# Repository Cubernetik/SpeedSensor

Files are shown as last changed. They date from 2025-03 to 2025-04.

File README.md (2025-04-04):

# ESP32 Timer-Based Pulse Distance Measurement

This is the source code to test an optical sensor to measure speed by time and distance. I use it for my experimental rail gun,
specifically for auto tuning the coil timing to maximize speed. This is an experiment and will not result in a rail gun with
notable projectile energy and is a mere physics experiment.

This implementation demonstrates how to measure the distance (time difference) between two GPIO pulses using the ESP32. It uses
hardware-level timers for precise measurement and ensures correct handling of timer overflows. The solution accounts for GPIO interrupts,
timer configurations, and overflow management.

## How It Works

  - GPIO Setup: The two GPIO pins (26 and 27) are set as inputs, and interrupts are attached to both to trigger on the rising edge of the signal.
  - Interrupt Service Routines (ISRs): The ISRs capture the current time (using the timer's counter) when a rising edge is detected.
  - Timer Configuration: A timer is configured to run with 1 µs resolution, allowing precise time tracking for the pulse measurement.
  - Time Difference Calculation: When both GPIO pins trigger, the time difference is calculated using the stored timer values. The calculation
    handles the potential timer overflow, ensuring the result remains accurate.

## Future Improvements

  - Higher Precision: The system can be adapted for higher-speed measurements by increasing timer resolution or using more advanced techniques like      the RMT peripheral.

## Conclusion

## Model files
Model files for 3D printing are available here: https://makerworld.com/en/models/1217145-speed-sensor-tube#profileId-1233233

## Schematic
Schematic for the IR proximity sensor board. Schematic and board located in kicad folder.
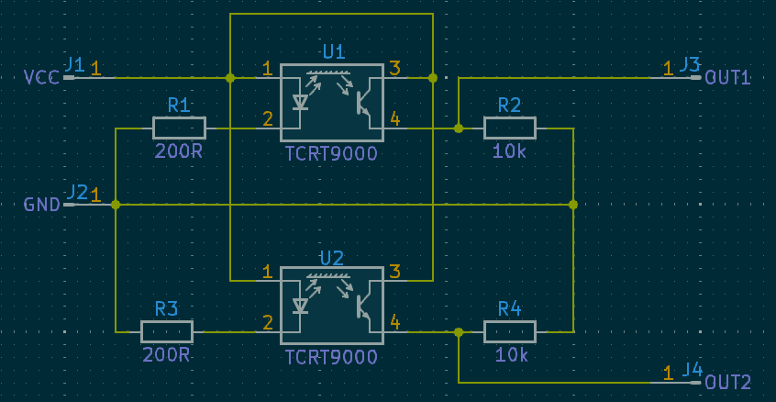
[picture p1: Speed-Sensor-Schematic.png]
IR proximity sensor board


## Example Measurements
The relative error shows room for improvement. Unfortunately lacking a RS flip flop to make a rising and a falling edge out of the two
rising edges. Once I have this done I will use RMT to count the distance of those two edges which can be done with 12.5 ns resolution
on hardware level. The precision should be sufficient after this change.
 - Time = 45332 µs, Speed = 0.662 m/s (2.38 km/h)
 - Time = 46816 µs, Speed = 0.641 m/s (2.31 km/h)
 - Time = 42106 µs, Speed = 0.712 m/s (2.56 km/h)
 - Time = 43452 µs, Speed = 0.690 m/s (2.49 km/h)

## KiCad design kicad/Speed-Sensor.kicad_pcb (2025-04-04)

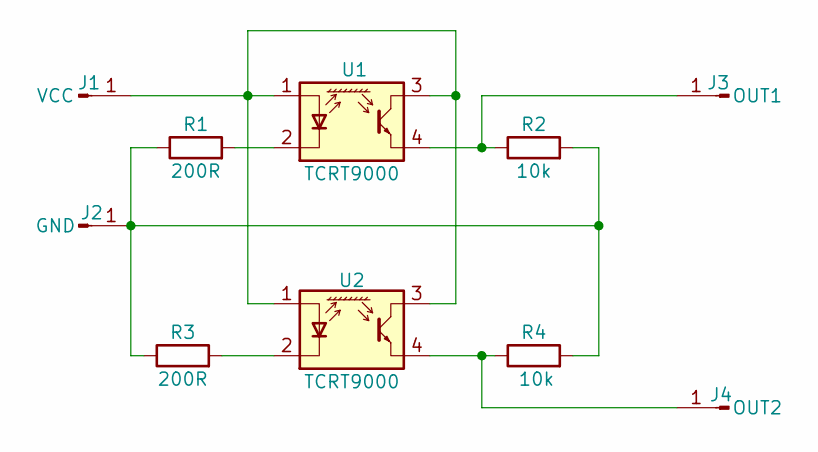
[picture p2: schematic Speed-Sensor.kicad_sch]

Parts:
J1: VCC; TestPoint_THTPad_2.0x2.0mm_Drill1.0mm
J2: GND; TestPoint_THTPad_2.0x2.0mm_Drill1.0mm
J3: OUT1; TestPoint_THTPad_2.0x2.0mm_Drill1.0mm
J4: OUT2; TestPoint_THTPad_2.0x2.0mm_Drill1.0mm
R1: 200R; R_Axial_DIN0204_L3.6mm_D1.6mm_P5.08mm_Horizontal
R2, R4: 10k; R_Axial_DIN0204_L3.6mm_D1.6mm_P5.08mm_Vertical
R3: 200R; R_Axial_DIN0204_L3.6mm_D1.6mm_P5.08mm_Vertical
U1, U2: TCRT9000

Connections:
unnamed: J1.1, U1.1 (A), U1.3 (C), U2.1 (A), U2.3 (C)
unnamed: J2.1, R1.1, R2.2, R3.1, R4.2
unnamed: J3.1, R2.1, U1.4 (E)
unnamed: J4.1, R4.1, U2.4 (E)
unnamed: R1.2, U1.2 (K)
unnamed: R3.2, U2.2 (K)

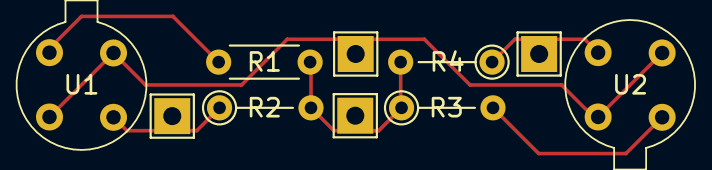
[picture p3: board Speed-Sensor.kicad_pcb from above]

Board: 2 copper layers, 10 parts (0 on the bottom side), 6 nets.

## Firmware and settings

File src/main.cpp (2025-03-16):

#include <Arduino.h>
#include "driver/rmt.h"
#include "driver/timer.h"

#define SENSOR_PIN_START 	GPIO_NUM_27
#define SENSOR_PIN_END 		GPIO_NUM_26

#define SENSOR_DISTANCE 	0.03 							// Distance between sensors in meters
#define TIMER_TICKS_PER_US 	1000000 						// 1µs per tick (make sure to use values which result in integer timer divider)
#define TIMER_DIVIDER 		80000000 / TIMER_TICKS_PER_US	// 80 MHz clock

volatile uint32_t timeStart = 0;
volatile uint32_t timeEnd = 0;
volatile uint32_t timeDiff = 0;
volatile bool timeIsValid = false;

// Capture start time
void IRAM_ATTR isrStartTime() 
{
	// Capture only once and ignore disturbances
	if (timeStart == 0)
	{
		timeStart = timer_group_get_counter_value_in_isr(TIMER_GROUP_0, TIMER_0);
	}
}

// Capture end time
void IRAM_ATTR isrEndTime() 
{
	// Do not capture if no start time which means opposite sensor triggered first
	if (timeStart > 0)
	{
		timeEnd = timer_group_get_counter_value_in_isr(TIMER_GROUP_0, TIMER_0);

		if (timeEnd > timeStart)
			timeDiff = timeEnd - timeStart;
		// Calculate with overflow
		else
			timeDiff = UINT32_MAX - timeStart + timeEnd;

		timeEnd = 0;
		timeStart = 0;
		timeIsValid = true;
	}
}

void setup() 
{
	Serial.begin(115200);

	// Configure GPIO pins as inputs
	pinMode(SENSOR_PIN_START, INPUT);
	pinMode(SENSOR_PIN_END, INPUT);

	// Attach interrupt handlers for both GPIOs
	attachInterrupt(SENSOR_PIN_START, isrStartTime, RISING);
	attachInterrupt(SENSOR_PIN_END, isrEndTime, RISING);

	// Initialize timer
	timer_config_t config = {
		.alarm_en = TIMER_ALARM_EN,
		.counter_en = TIMER_START,
		.counter_dir = TIMER_COUNT_UP,
		.auto_reload = TIMER_AUTORELOAD_EN,
		.divider = TIMER_DIVIDER
	};
	timer_init(TIMER_GROUP_0, TIMER_0, &config);
	timer_set_counter_value(TIMER_GROUP_0, TIMER_0, 0);  // Start timer at 0
}

void loop() 
{
	if (timeIsValid) 
	{
		float timeDiffSec = (float)timeDiff / TIMER_TICKS_PER_US;
		float speed = SENSOR_DISTANCE / timeDiffSec;

		Serial.printf("Time = %u µs, Speed = %.3f m/s (%.2f km/h)\n", timeDiff, speed, speed * 3.6);
		timeIsValid = false;
	}
}

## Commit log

2025-04-04 Add schematic for IR proximity sensors
2025-04-04 Add schematic to README.md
2025-04-04 Add kicad files for IR proximity sensor PCB
    [Speed-Sensor.kicad_pcb, Speed-Sensor.kicad_sch]
2025-04-04 Added reference to kicad files to README.md
